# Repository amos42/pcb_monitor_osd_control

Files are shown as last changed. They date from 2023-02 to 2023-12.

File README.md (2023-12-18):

# Monitor OSD Control Board

---

[모니터 OSD 컨트롤 버튼 보드](monitor_osd_control/)
([README.md](monitor_osd_control/README.md))

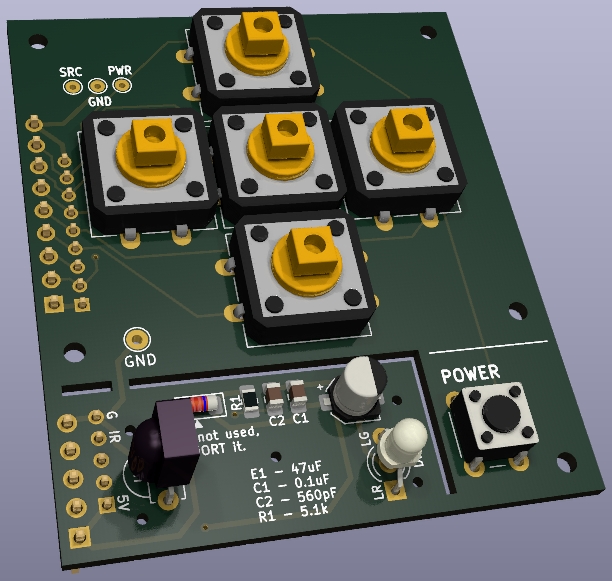
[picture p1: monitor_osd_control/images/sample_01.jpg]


---

[iPAD LCD용 OSD 컨트롤 버튼 보드](ipad_osd_control/)
([README.md](ipad_osd_control/README.md))

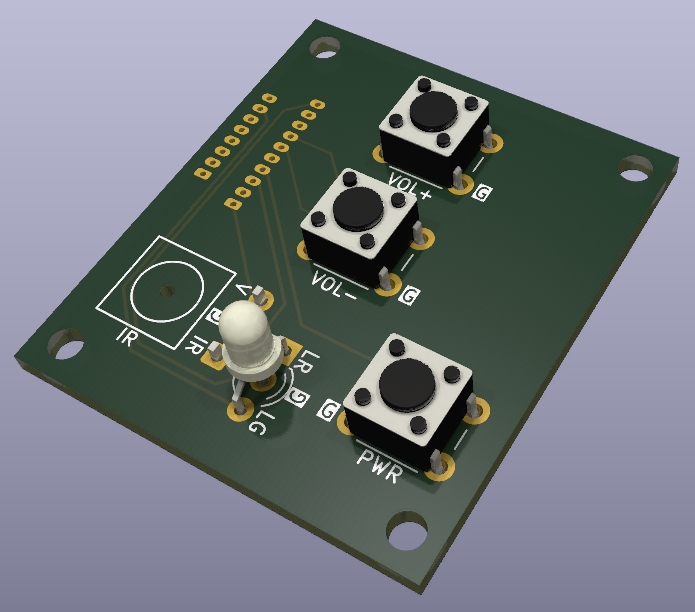
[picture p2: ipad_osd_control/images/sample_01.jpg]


---

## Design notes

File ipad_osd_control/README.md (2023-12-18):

# Monitor OSD Control Board (for iPAD LCD)

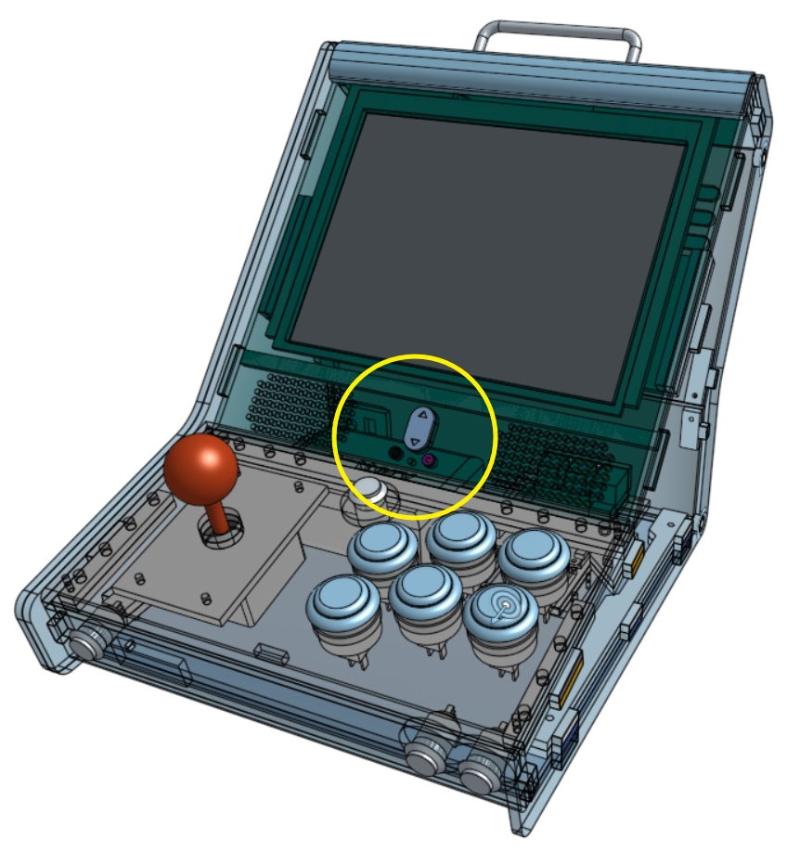
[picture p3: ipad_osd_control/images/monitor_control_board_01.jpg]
4방향 버튼 부착 기구물


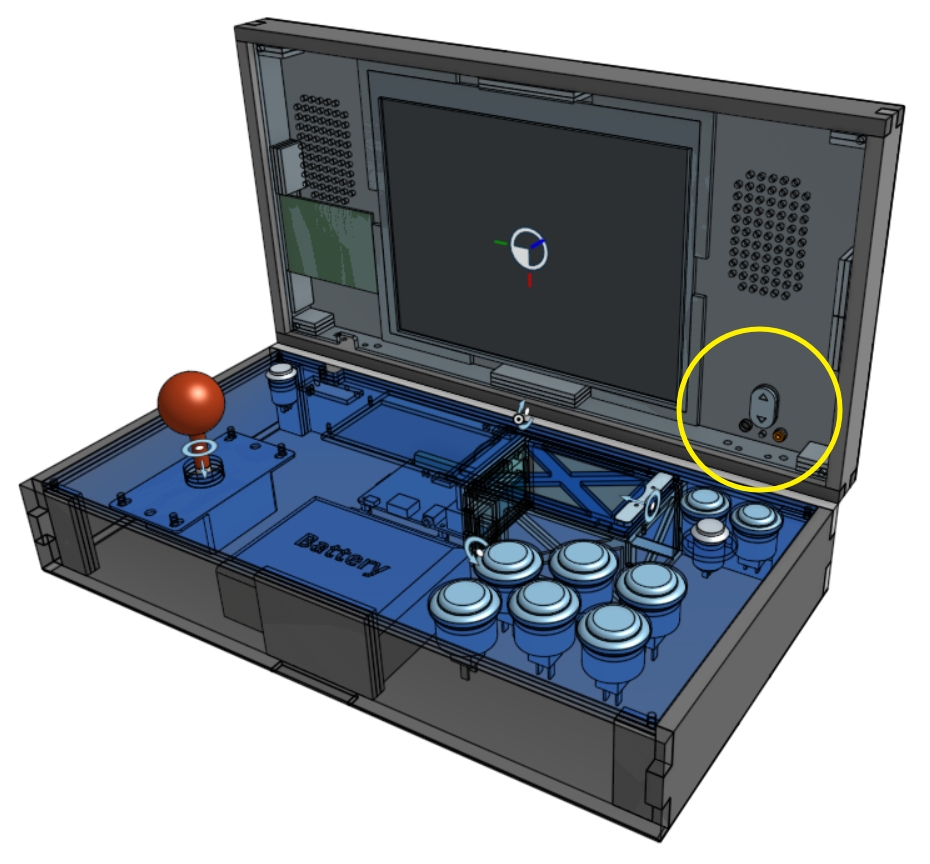
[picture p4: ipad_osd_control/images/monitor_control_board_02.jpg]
4방향 버튼 적용


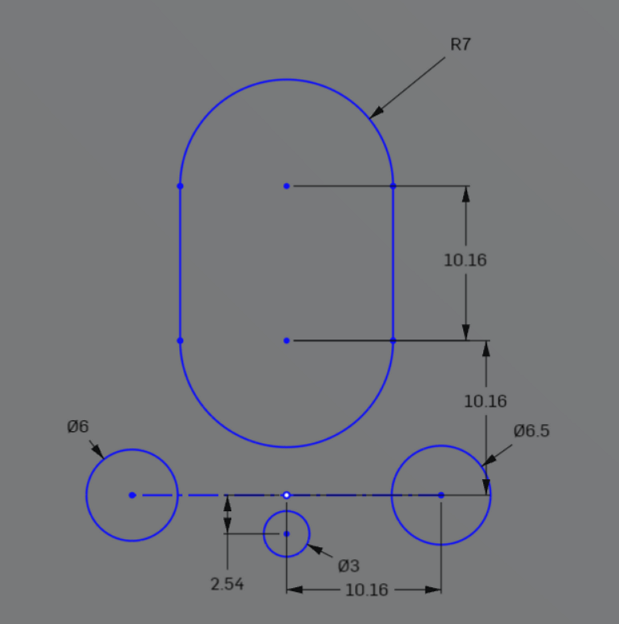
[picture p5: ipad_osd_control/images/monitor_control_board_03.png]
4방향 버튼 보드 레이아웃


회로도

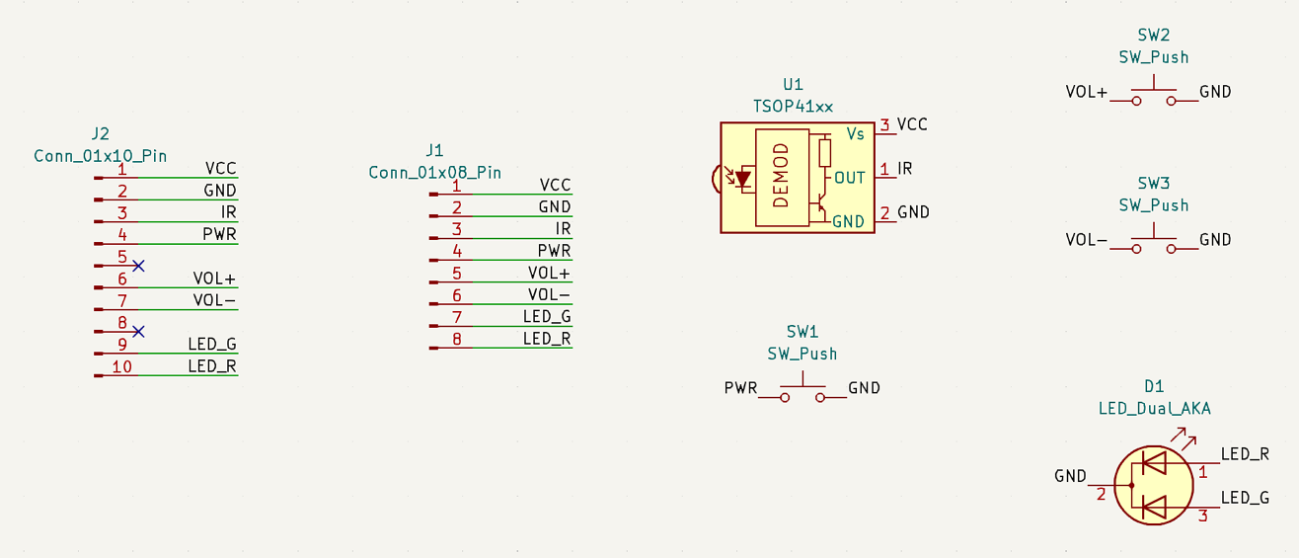
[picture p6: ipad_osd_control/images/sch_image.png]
회로도


PCB 이미지

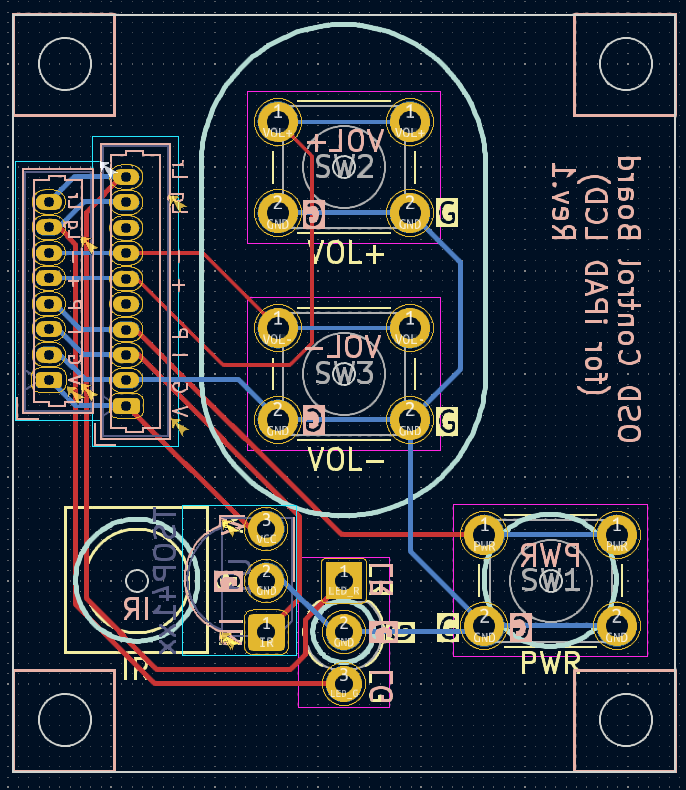
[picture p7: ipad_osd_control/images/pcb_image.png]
PCB


샘플 이미지

샘플 앞면

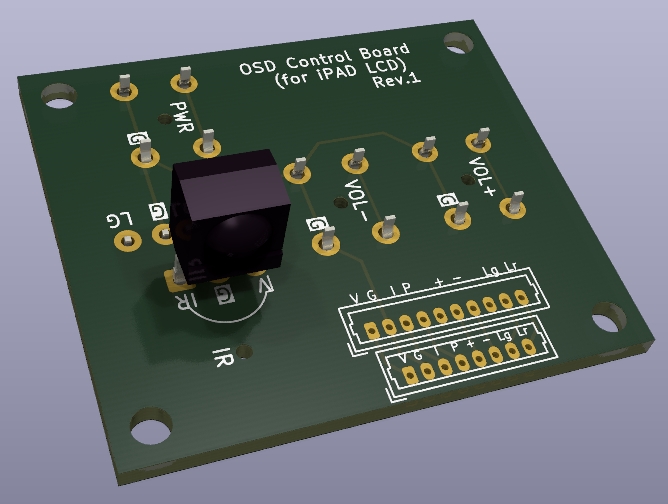
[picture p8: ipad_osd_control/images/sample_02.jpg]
샘플 뒷면


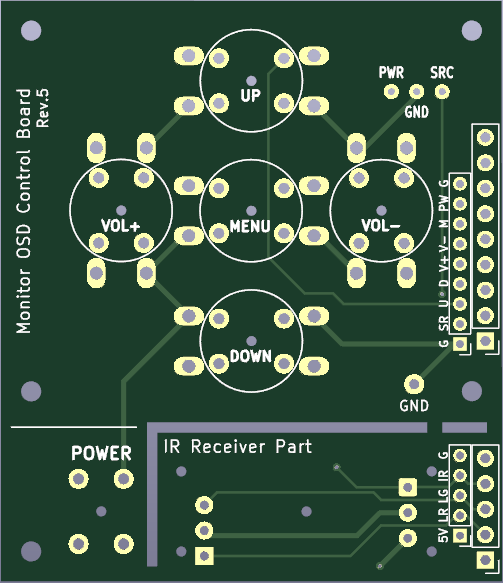
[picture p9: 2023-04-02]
monitor_osd_control/images/pcb_image_03.png

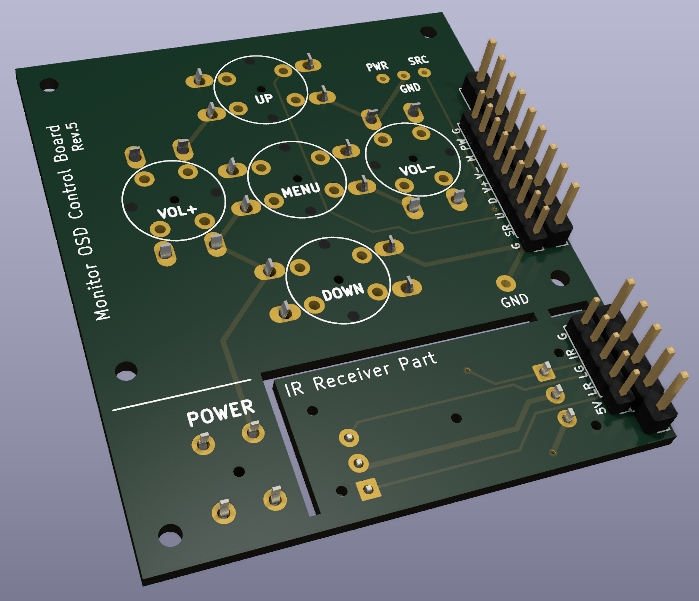
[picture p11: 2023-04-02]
monitor_osd_control/images/sample_02.jpg

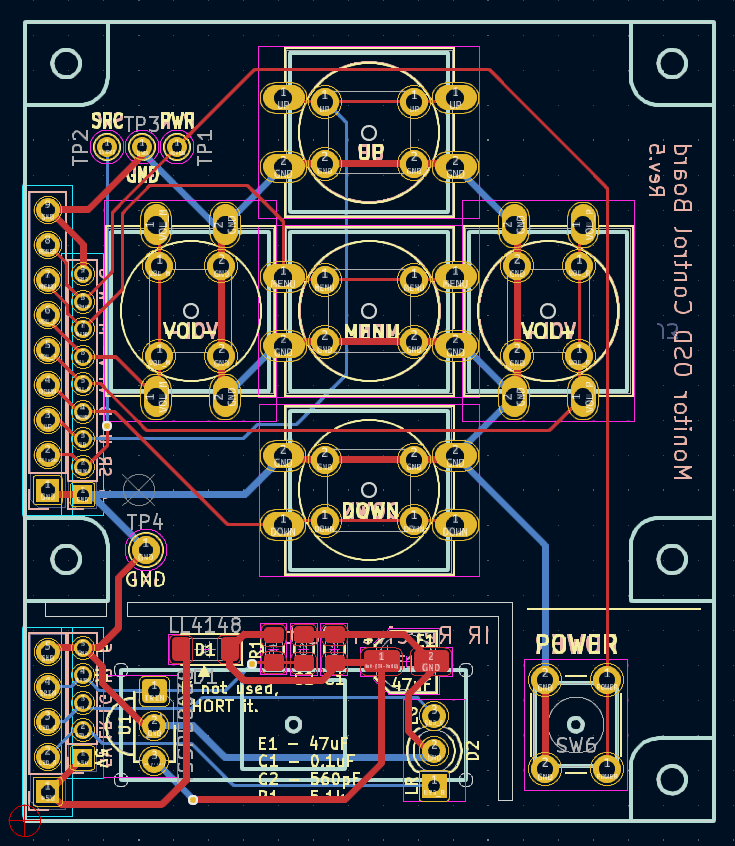
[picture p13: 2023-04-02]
monitor_osd_control/images/pcb_image.png

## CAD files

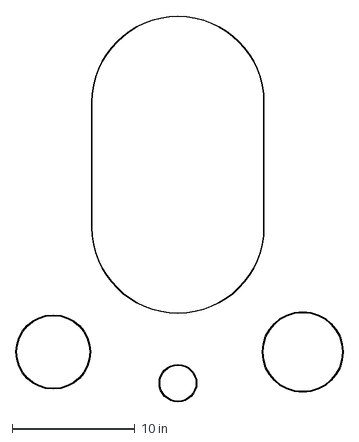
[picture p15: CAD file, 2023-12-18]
ipad_osd_control/tiny_osd.dxf
26.6 x 31.4 in

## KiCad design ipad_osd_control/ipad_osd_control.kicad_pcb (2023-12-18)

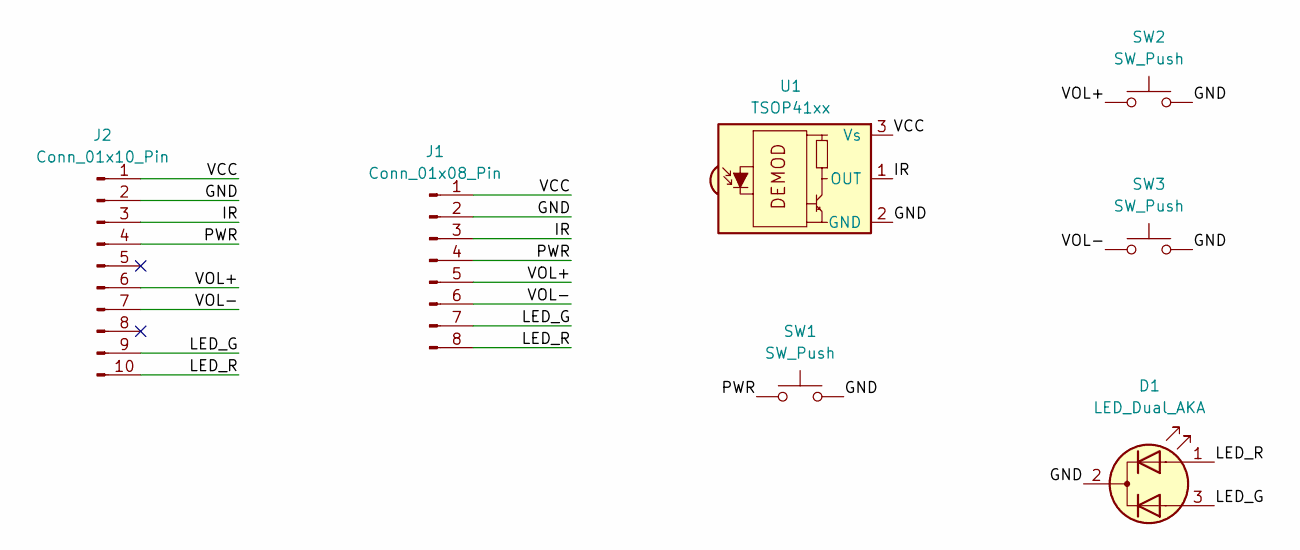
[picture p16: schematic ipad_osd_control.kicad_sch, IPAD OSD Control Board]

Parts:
D1: LED_Dual_AKA; LED_D3.0mm-3
J1: Conn_01x08_Pin; Molex_PicoBlade_53047-0810_1x08_P1.25mm_Vertical
J2: Conn_01x10_Pin; Molex_PicoBlade_53047-1010_1x10_P1.25mm_Vertical
SW1, SW2, SW3: SW_Push; SW_PUSH_6mm
U1: TSOP41xx; Vishay_MOLD-3Pin

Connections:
/GND: D1.2 (K), J1.2, J2.2, SW1.2, SW2.2, SW3.2, U1.2 (GND)
/IR: J1.3, J2.3, U1.1 (OUT)
/LED_G: D1.3 (A2), J1.7, J2.9
/LED_R: D1.1 (A1), J1.8, J2.10
/PWR: J1.4, J2.4, SW1.1
/VCC: J1.1, J2.1, U1.3 (Vs)
/VOL+: J1.5, J2.6, SW2.1
/VOL-: J1.6, J2.7, SW3.1

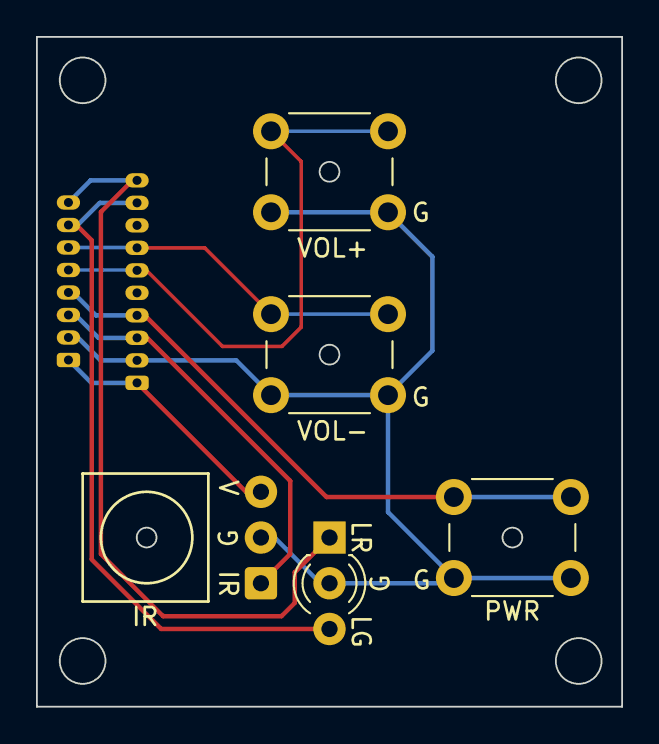
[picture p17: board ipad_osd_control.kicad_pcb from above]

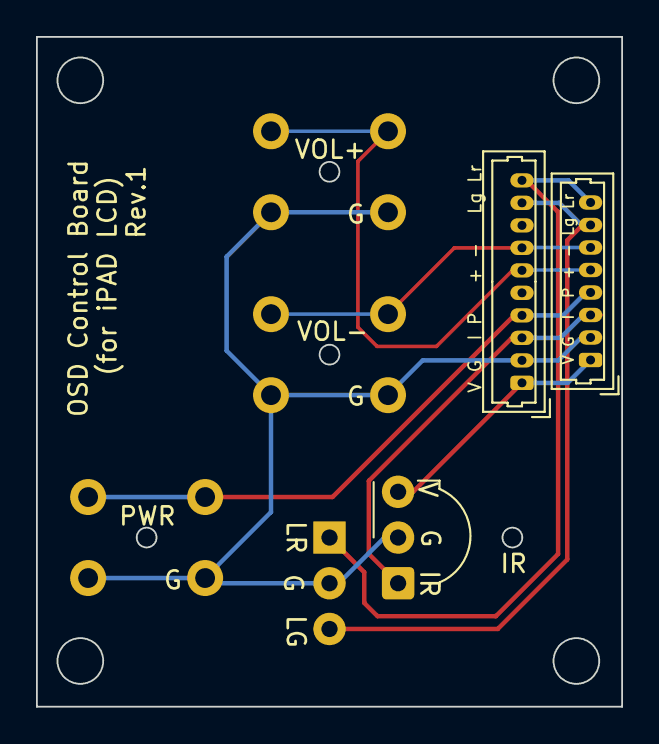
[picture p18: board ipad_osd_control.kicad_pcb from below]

Board: 2 copper layers, 32.5 x 37.2 mm, 7 parts (3 on the bottom side), 8 nets.

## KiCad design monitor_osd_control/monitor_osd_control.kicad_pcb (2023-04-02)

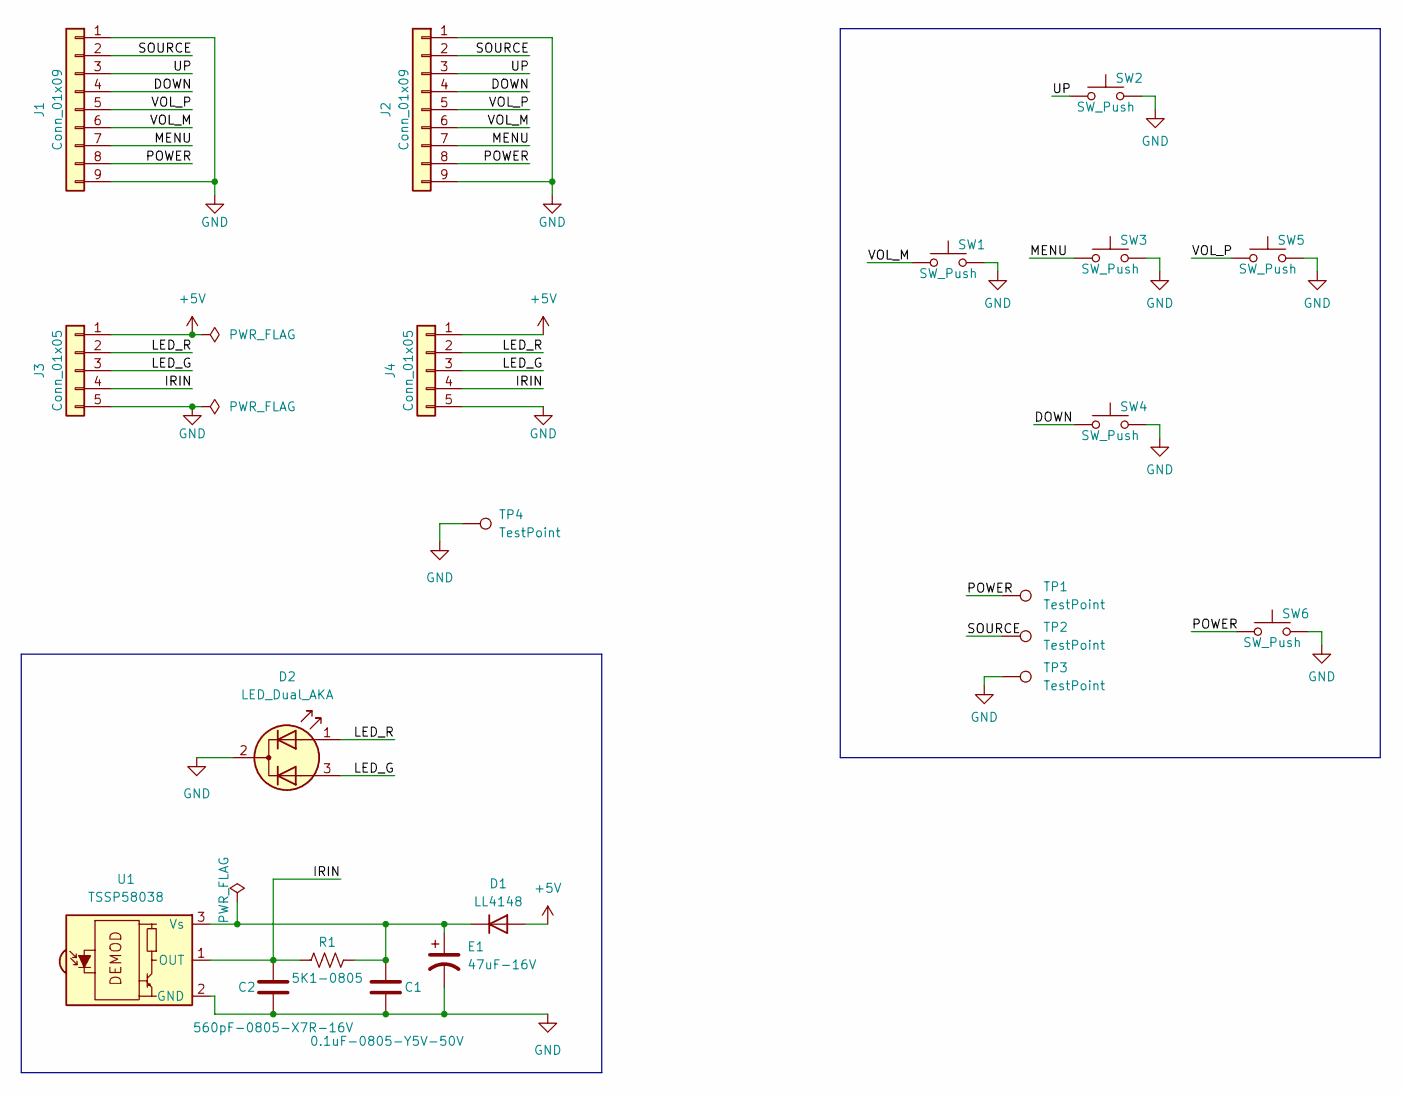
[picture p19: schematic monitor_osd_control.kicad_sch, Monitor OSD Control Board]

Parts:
C1: 0.1uF-0805-Y5V-50V; C_0805_2012Metric_Pad1.18x1.45mm_HandSolder
C2: 560pF-0805-X7R-16V; C_0805_2012Metric_Pad1.18x1.45mm_HandSolder
D1: LL4148; D_MiniMELF
D2: LED_Dual_AKA; LED_D3.0mm-3
E1: 47uF-16V; CP_Elec_5x5.4
J1: Conn_01x09; PinHeader_1x09_P2.00mm_Vertical
J2: Conn_01x09; PinHeader_1x09_P2.54mm_Vertical
J3: Conn_01x05; PinHeader_1x05_P2.00mm_Vertical
J4: Conn_01x05; PinHeader_1x05_P2.54mm_Vertical
R1: 5K1-0805; R_0805_2012Metric_Pad1.20x1.40mm_HandSolder
SW1, SW2, SW3, SW4, SW5: SW_Push; SW_PUSH-12mm_Complex
SW6: SW_Push; SW_PUSH_6mm
TP1, TP2, TP3: TestPoint; TestPoint_THTPad_D1.5mm_Drill0.7mm
TP4: TestPoint; TestPoint_THTPad_D2.0mm_Drill1.0mm
U1: TSSP58038; Vishay_MINICAST-3Pin

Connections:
+5V: D1.2 (A), J3.1, J4.1
/DOWN: J1.4, J2.4, SW4.1
/IRIN: C2.1, J3.4, J4.4, R1.1, U1.1 (OUT)
/LED_G: D2.3 (A2), J3.3, J4.3
/LED_R: D2.1 (A1), J3.2, J4.2
/MENU: J1.7, J2.7, SW3.1
/POWER: J1.8, J2.8, SW6.1, TP1.1
/SOURCE: J1.2, J2.2, TP2.1
/UP: J1.3, J2.3, SW2.1
/VOL_M: J1.6, J2.6, SW1.1
/VOL_P: J1.5, J2.5, SW5.1
GND: C1.2, C2.2, D2.2 (K), E1.2, J1.1, J1.9, J2.1, J2.9, J3.5, J4.5, SW1.2, SW2.2, SW3.2, SW4.2, SW5.2, SW6.2, TP3.1, TP4.1, U1.2 (GND)
unnamed: C1.1, D1.1 (K), E1.1, R1.2, U1.3 (Vs)

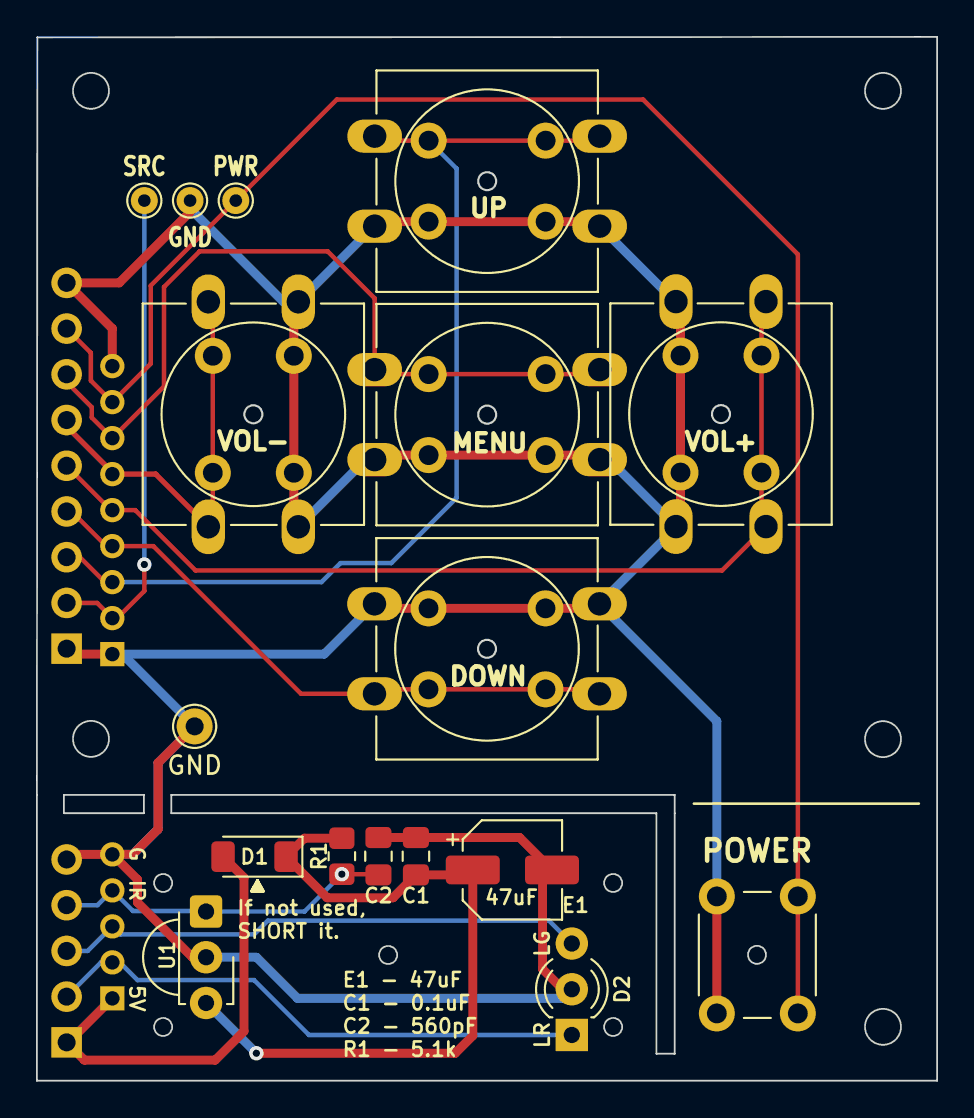
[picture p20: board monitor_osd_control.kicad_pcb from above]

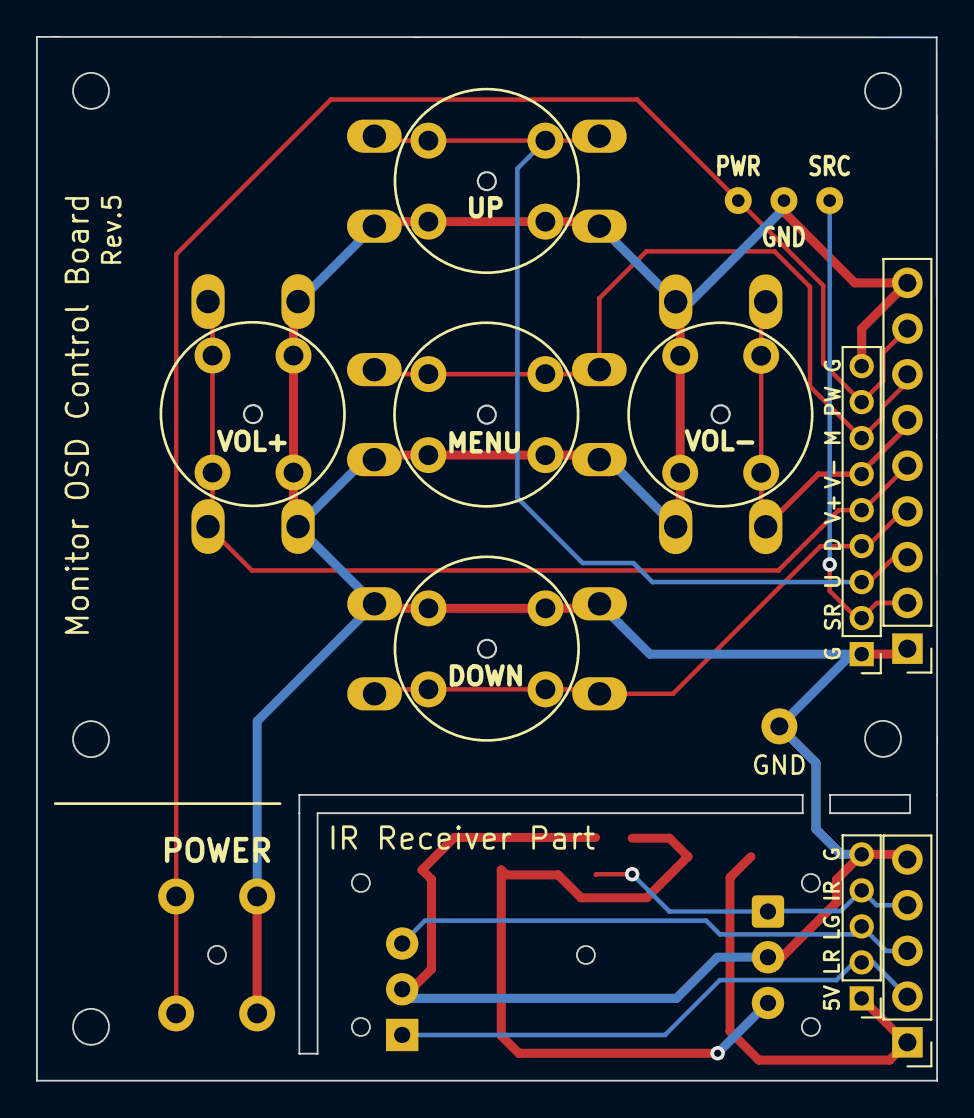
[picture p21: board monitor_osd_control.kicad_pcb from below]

Board: 2 copper layers, 50.0 x 58.0 mm, 21 parts (4 on the bottom side), 13 nets.

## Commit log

2023-02-12 배선 최적화 및 pretty 경로 보정
    [monitor_osd_control-B_Cu.gbr, monitor_osd_control-B_Mask.gbr, monitor_osd_control-B_Paste.gbr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]
2023-03-11 커넥터 위치 미세하게 안쪽으로 조정
    [monitor_osd_control-B_Cu.gbr, monitor_osd_control-B_Mask.gbr, monitor_osd_control-B_Paste.gbr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]
2023-03-11 gitignore 파일 추가
2023-03-26 버튼을 12mm와 6mm 겸용으로
    [monitor_osd_control-B_Cu.gbr, monitor_osd_control-B_Mask.gbr, monitor_osd_control-B_Paste.gbr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]
2023-03-28 Rev 5로 업데이트
    - 버튼을 12mm 6mm 공용으로 사용 가능하도록 수정
    - 마우스 바이트 제거
    [monitor_osd_control-B_Cu.gbr, monitor_osd_control-B_Mask.gbr, monitor_osd_control-B_Paste.gbr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]
2023-04-02 캐패시터 크기 변경
    [monitor_osd_control-B_Cu.gbr, monitor_osd_control-B_Mask.gbr, monitor_osd_control-B_Paste.gbr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]
2023-04-02 GND 면적 증가
    [monitor_osd_control-B_Cu.gbr, monitor_osd_control-B_Mask.gbr, monitor_osd_control-B_Paste.gbr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]
2023-12-18 ipad용 LCD OSD 컨트롤 보드 추가
    [ipad_osd_control-B_Cu.gbr, ipad_osd_control-B_Mask.gbr, ipad_osd_control-B_Paste.gbr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]
